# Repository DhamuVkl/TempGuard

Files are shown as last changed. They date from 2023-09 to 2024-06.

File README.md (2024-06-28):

<br/>
<p align="center">
  <a href="https://github.com/dhamuvkl/TempGuard">
    
  </a>

  <h3 align="center">TempGuard</h3>

  <p align="center">
    A sophisticated temperature control system designed for industrial heating applications. It employs a unique approach by utilizing an IRFZ44N MOSFET as a temperature sensor!
    <br/>
    <br/>
  </p>
</p>

    

## Table Of Contents

* [About the Project](#about-the-project)
* [Key Features](#key-features)
* [Technologies Used](#technologies-used)
* [Schematics & Fabrication](#schematics-and-fabrication)
* [Roadmap](#roadmap)
* [Contributing](#contributing)
* [License](#license)
* [Struggles Faced during Development](#struggles-faced-during-development)
* [Author](#author)

## About The Project



**TempGuard** is a sophisticated temperature control system designed for industrial heating applications. It employs a unique approach by utilizing an IRFZ44N MOSFET as a temperature sensor, enabling precise temperature measurements. This innovative system, driven by a BluePill microcontroller (STM32F103C8T6), ensures heating elements operate within desired temperature ranges. Additionally, it features a user interface for seamless adjustments.

##  Key Features: 

* **Overheating Prevention:** TempGuard prevents heating elements from overheating and potential damage, thus extending their operational lifespan.
  
* **Energy Efficiency:** By maintaining an optimal temperature range, the system reduces energy consumption, ultimately lowering electricity bills.  

* **Uniform Heating:** Ensures consistent temperature levels, eliminating issues associated with uneven heating, and thereby enhancing industrial processes.  

* **Versatility:** TempGuard's adaptability extends beyond industrial heating systems, making it suitable for a wide range of applications requiring precise temperature control.  

* **Robust Performance:** Engineered to function reliably under extreme temperature conditions, both in hot and cold environments.

  

## Technologies Used:

* **IRFZ44N MOSFET as Temperature Sensor:** This unconventional choice allows for accurate temperature measurements, enhancing the control of heating elements.

* **BluePill Microcontroller (STM32F103C8T6):** Responsible for crucial tasks including measuring MOSFET temperature values, controlling the relay board, and obtaining user-defined temperature settings.  

* **Relay System:** Vital for regulating the heating element based on the measured temperature values.  

* **User Interface with Switch:** Enables users to toggle between two predefined temperature settings, adding flexibility to the system.  

## Schematics and Fabrication 














## Roadmap

See the [open issues](https://github.com/dhamuvkl/TempGuard/issues) for a list of proposed features (and known issues).

## Contributing

Contributions are what make the open source community such an amazing place to be learn, inspire, and create. Any contributions you make are **greatly appreciated**.
* If you have suggestions for adding or removing projects, feel free to [open an issue](https://github.com/dhamuvkl/TempGuard/issues/new) to discuss it, or directly create a pull request after you edit the *README.md* file with necessary changes.
* Please make sure you check your spelling and grammar.
* Create individual PR for each suggestion.

## Struggles Faced during Development:
coding

* **Analog Prototype with OP-AMP (LM358):** The initial version of the prototype relied on an analog design, utilizing an LM358 OP-AMP in hysteresis mode. However, this approach proved sensitive to Electromagnetic Interference (EMI) during field tests.

* **EMI Sensitivity:** The analog design was susceptible to EMI, especially from electrical noise in the grid. This led to erratic switching of temperature set values, making the system unreliable.  

* **Transition to Digital Design:** To address the EMI sensitivity issue, a significant shift was made towards a digital approach. This involved integrating the BluePill microcontroller (STM32F103C8T6) to bring stability and robustness to the system's operation.

## License

Distributed under the MIT License. See [LICENSE](https://github.com/dhamuvkl/TempGuard/blob/main/LICENSE.md) for more information.

## Author

* **Dharageswaran S** - *Electronics Enthusiast | Innovator | Tech Visionary* - [Dharageswaran S](https://github.com/DhamuVkl/) - *Owner *

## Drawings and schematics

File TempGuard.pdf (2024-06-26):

A

B

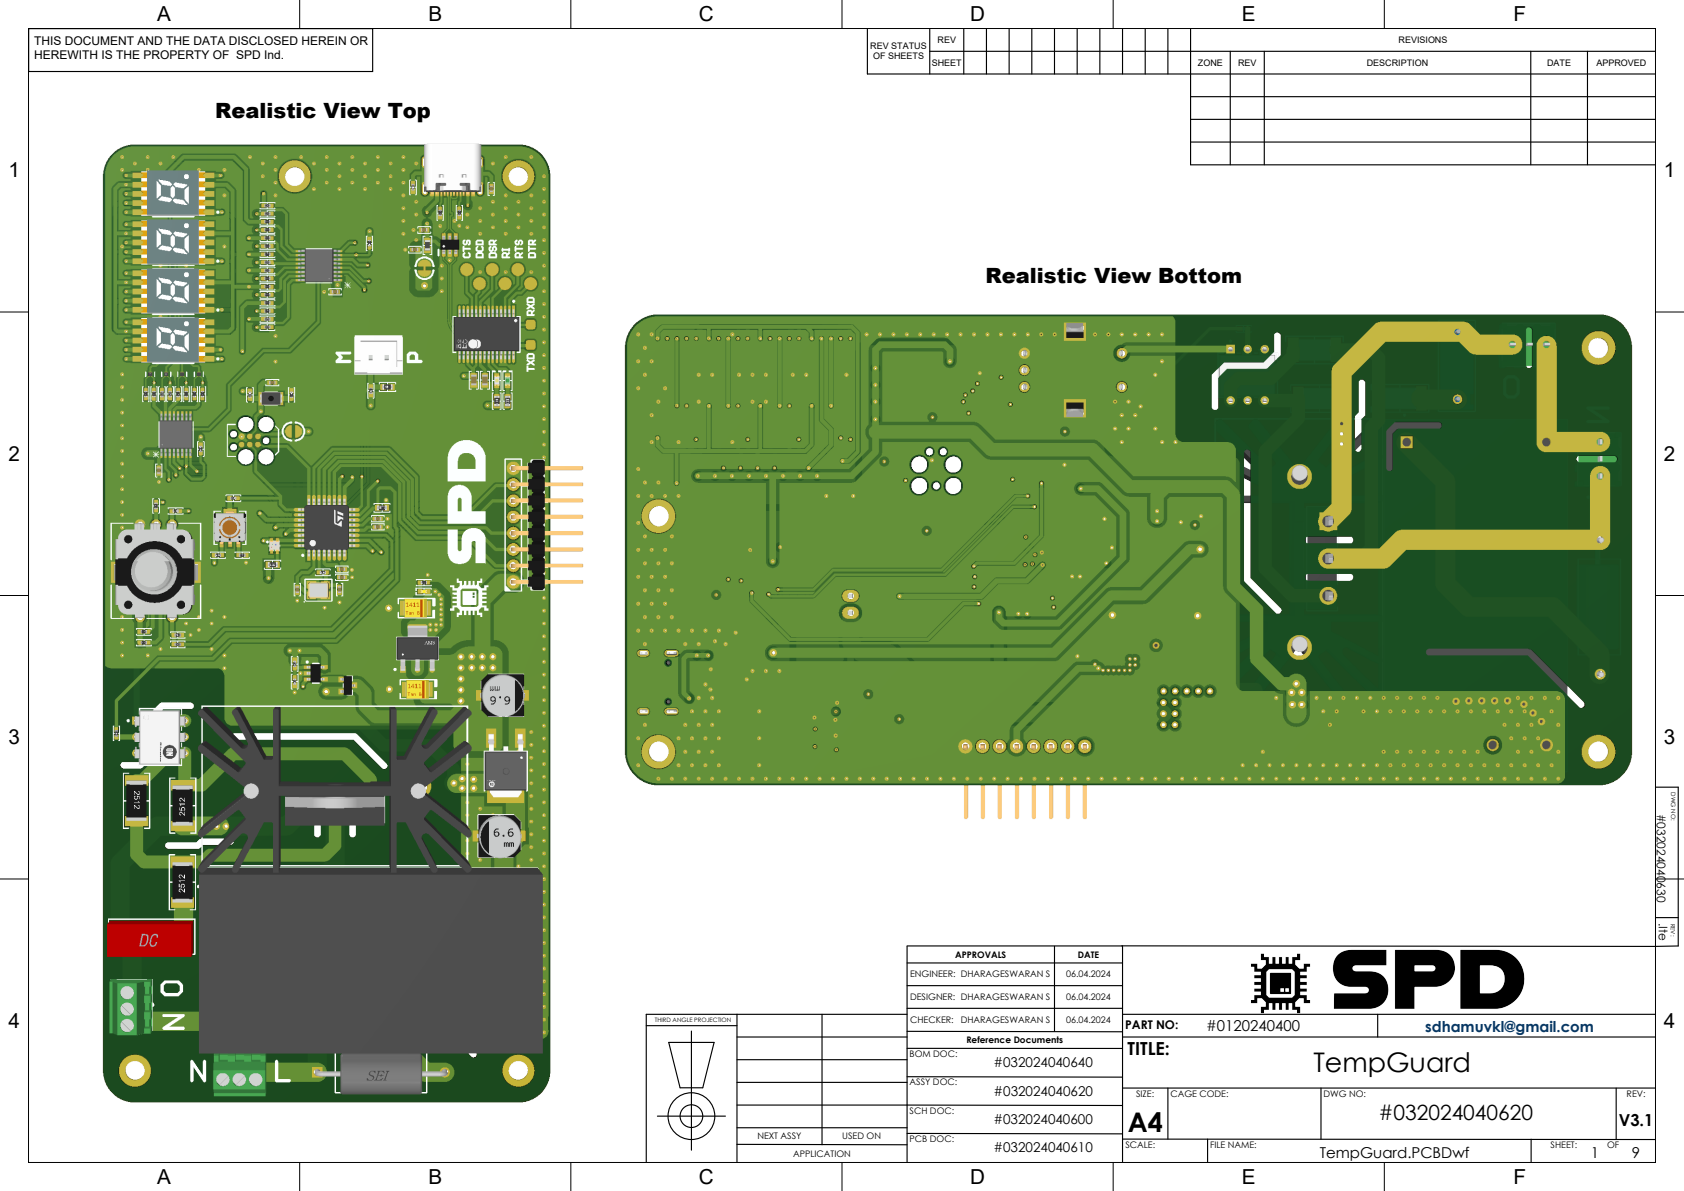
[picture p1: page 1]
sdhamuvkl@gmail.com; ZONE; REV; DESCRIPTION; DATE; APPROVED; REVISIONS; SHEET; REV STATUS OF SHEETS; REV:; SHEET:; DWG NO: #032024040630 .Ite; PART NO:; NEXT ASSY; USED ON; APPLICATION; TempGuard.PCBDwf #032024040610; FILE NAME:; Reference Documents #032024040640; SCH DOC:; PCB DOC:; ASSY DOC:; BOM DOC:; TempGuard; TITLE:; SCALE:; DWG NO:; SIZE:; CAGE CODE:

THIS DOCUMENT AND THE DATA DISCLOSED HEREIN OR
HEREWITH IS THE PROPERTY OF SPD Ind.

Realistic View Top

Realistic View Bottom

APPROVALS | DATE

ENGINEER: DHARAGESWARAN S | 06.04.2024

DESIGNER: DHARAGESWARAN S | 06.04.2024

THIRD ANGLE PROJECTION

CHECKER: DHARAGESWARAN S | 06.04.2024

1 | 1

U2B

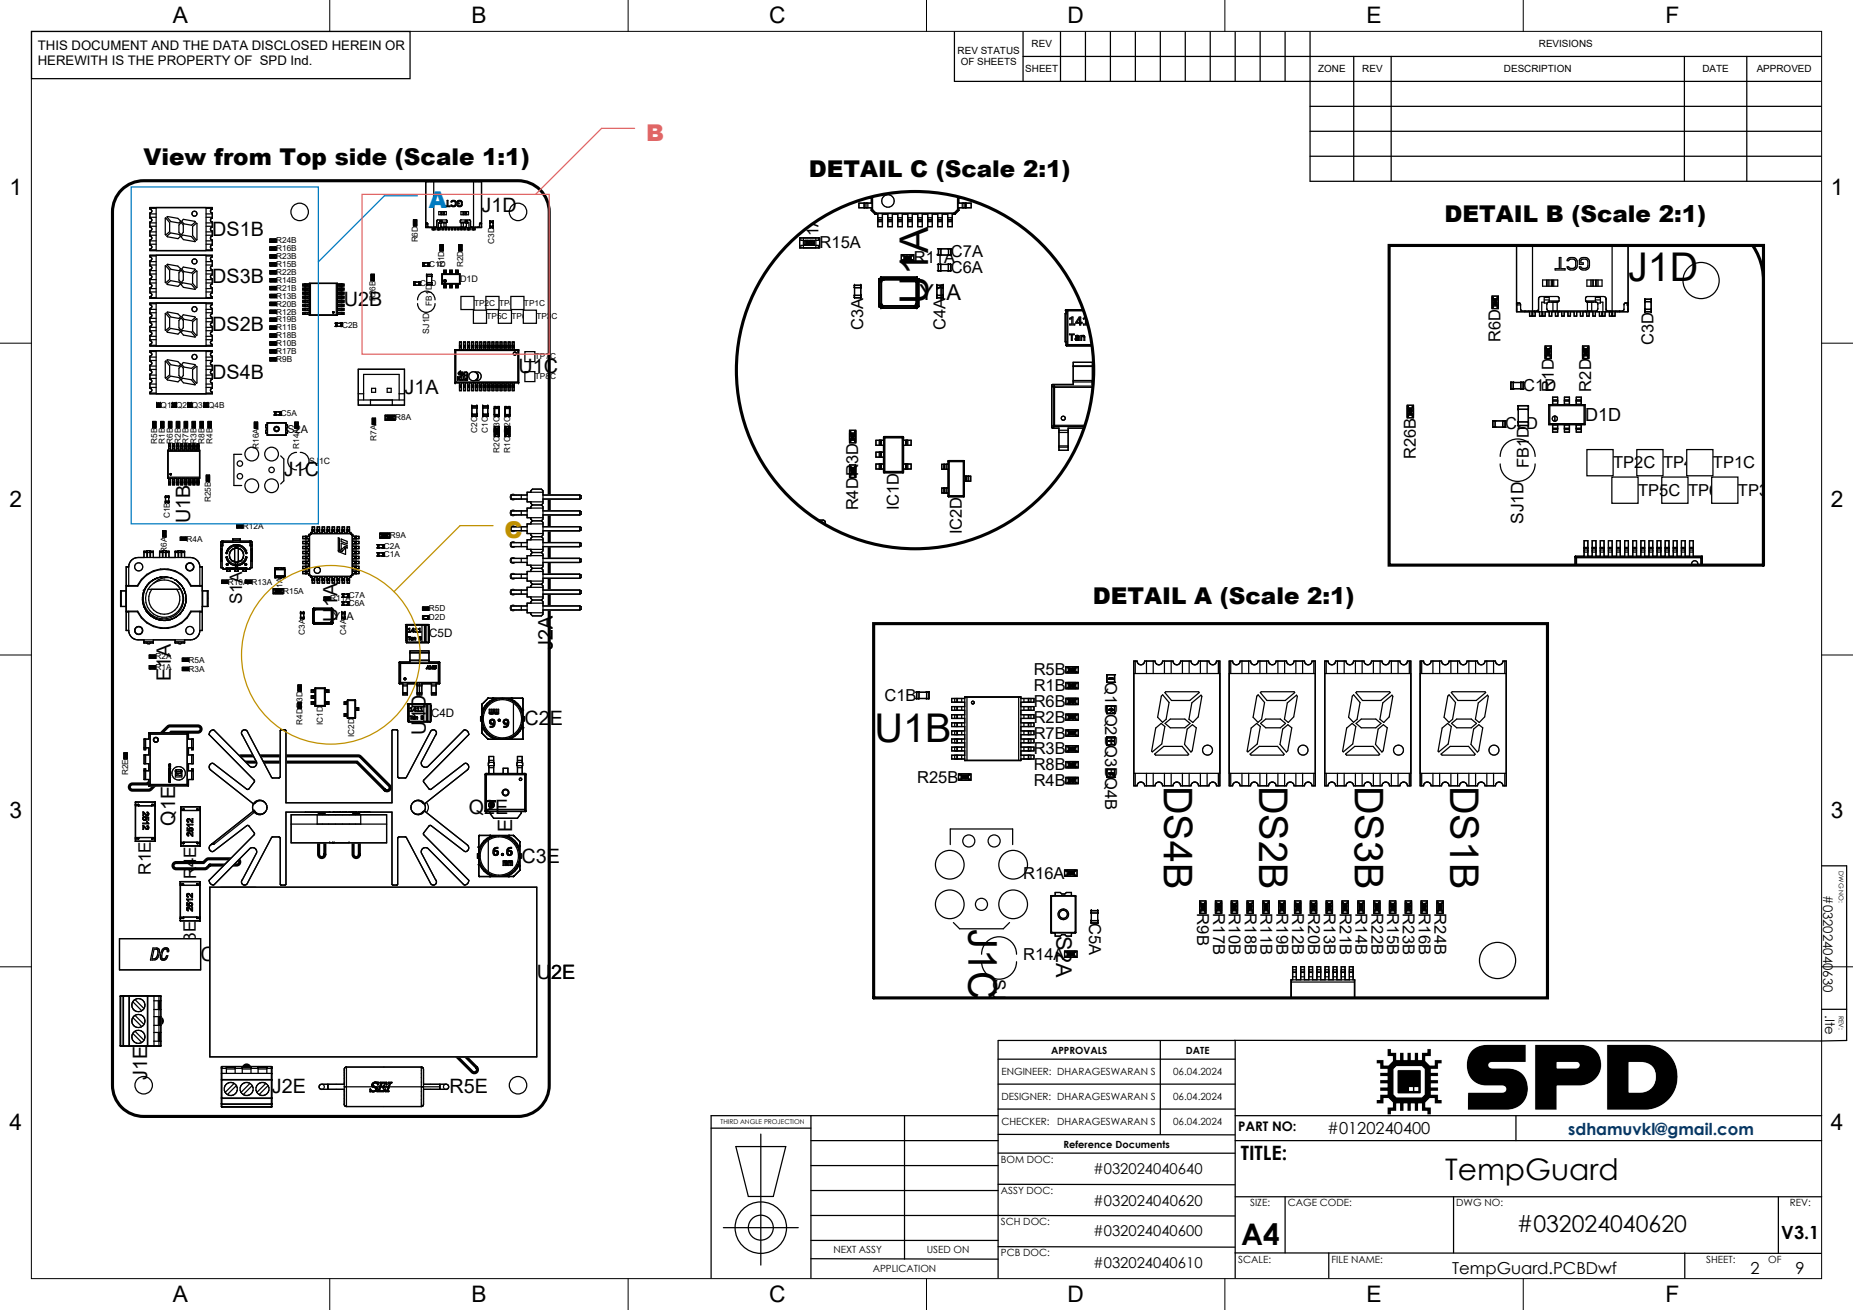
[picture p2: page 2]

View from Top side (Scale 1:1)

1 | 1

# View from Front side (Scale 1:1)

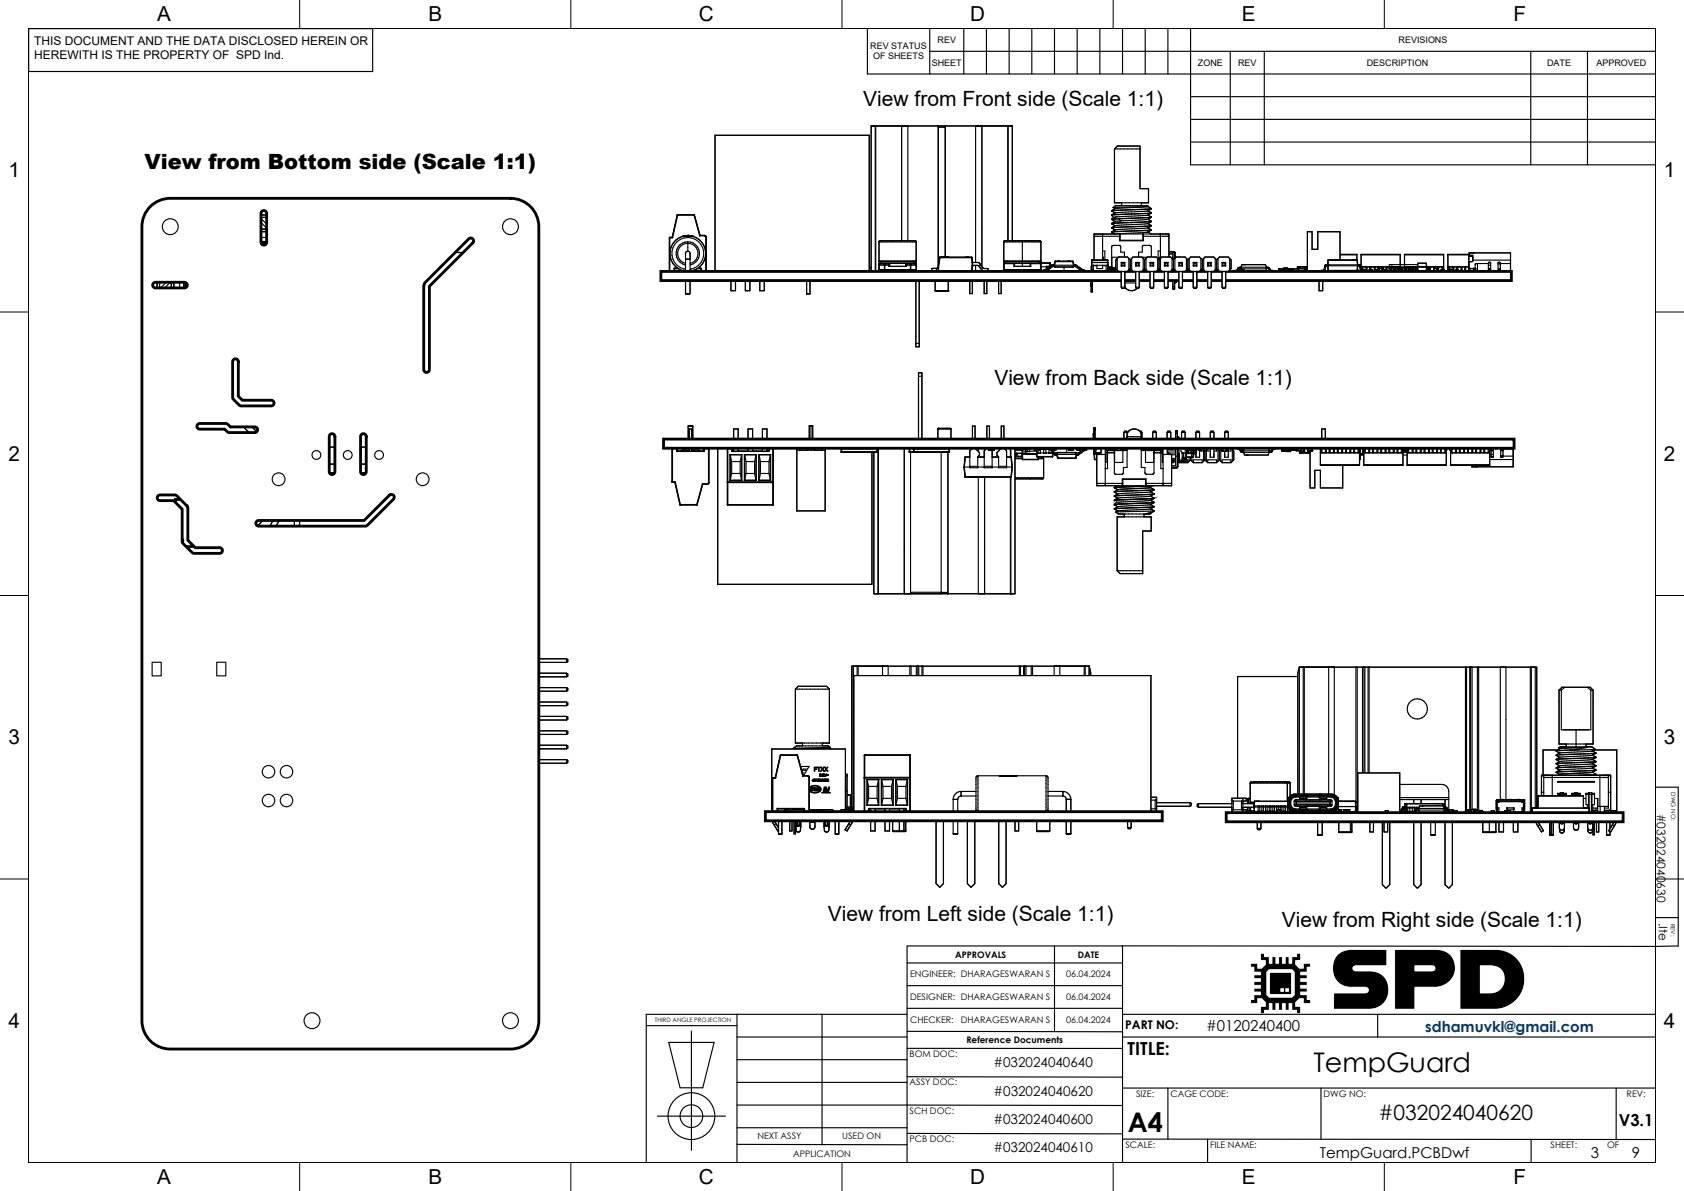
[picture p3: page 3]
DWG NO: #032024040630 .Ite; REV:; DHARAGESWARAN S; CHECKER:; DESIGNER:; ENGINEER:; APPROVALS; DATE; PART NO:; Reference Documents #032024040640; ASSY DOC:; BOM DOC:; TempGuard; TITLE:

View from Bottom side (Scale 1:1)

View from Back side (Scale 1:1)

View from Left side (Scale 1:1)

View from Right side (Scale 1:1)

THIRD ANGLE PROJECTION

sdhamuvkl@gmail.com

1 | 1

# Drill Drawing View (Scale 1.2:1)

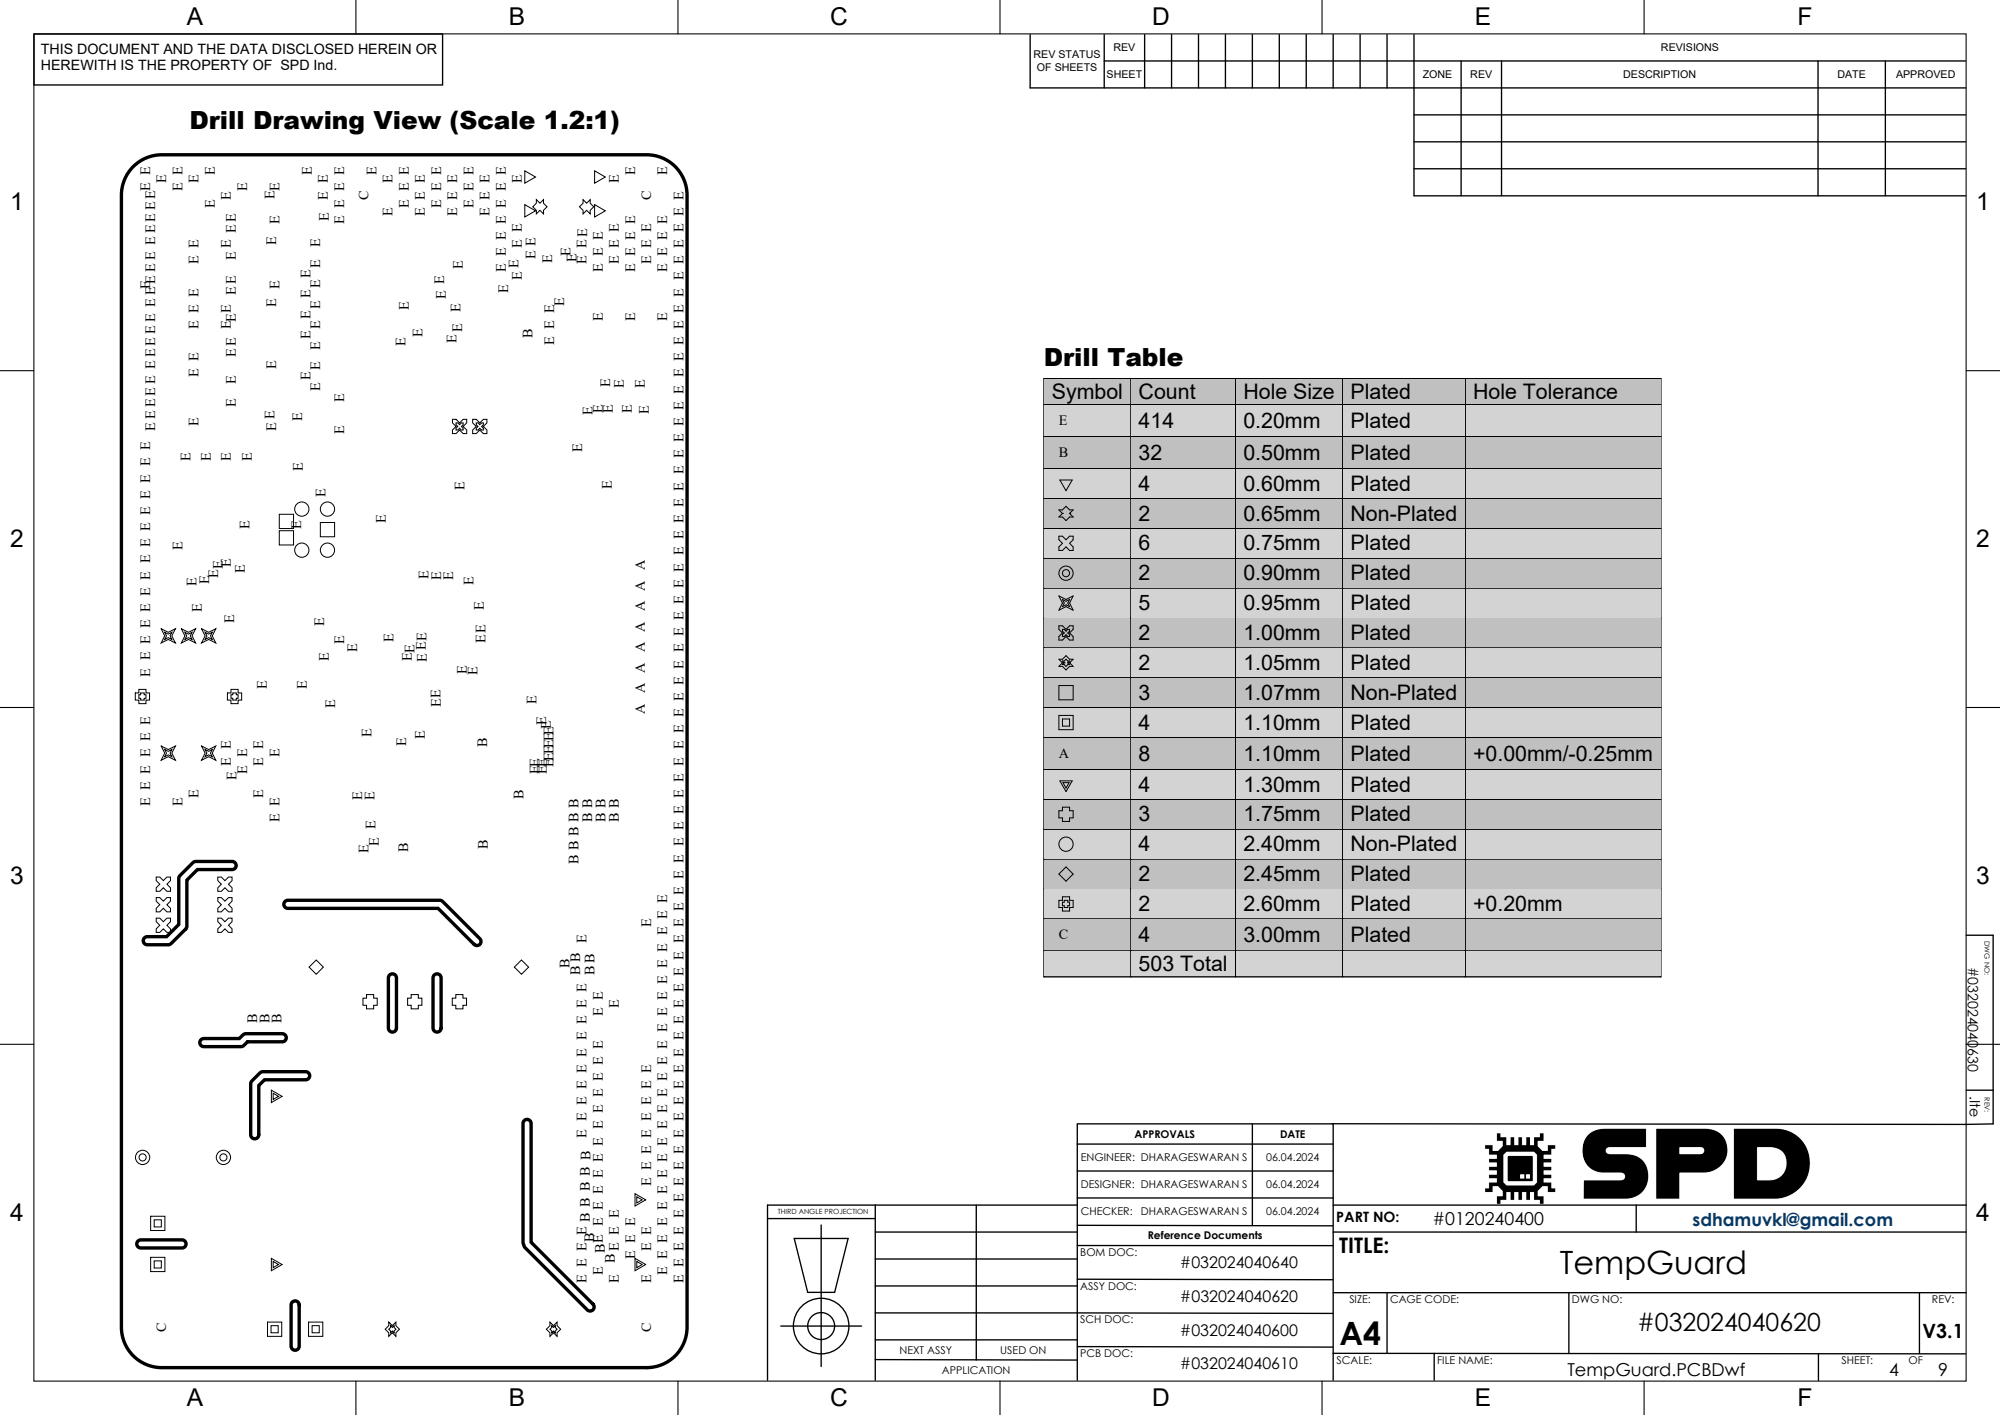
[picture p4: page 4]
B B B B B BBB; EEEE; E E EEE; DWG NO: #032024040630 .Ite; REV:; PART NO:; Reference Documents #032024040640; ASSY DOC:; BOM DOC:; TempGuard; TITLE:; Drill Table

Symbol | Count | Hole Size | Plated | Hole Tolerance
E | 414 | 0.20mm | Plated

B | 32 | 0.50mm | Plated

4 | 0.60mm | Plated
2 | 0.65mm | Non-Plated
6 | 0.75mm | Plated
2 | 0.90mm | Plated

5 | 0.95mm | Plated
2 | 1.00mm | Plated
2 | 1.05mm | Plated
3 | 1.07mm | Non-Plated

4 | 1.10mm | Plated

A | | | 8 | 1.10mm | Plated | +0.00mm/-0.25mm

4 | 1.30mm | Plated
3 | 1.75mm | Plated
4 | 2.40mm | Non-Plated
2 | 2.45mm | Plated
2 | 2.60mm | Plated | +0.20mm

C | | | 4 | 3.00mm | Plated

503 Total

APPROVALS | DATE

ENGINEER: DHARAGESWARAN S | 06.04.2024

DESIGNER: DHARAGESWARAN S | 06.04.2024

THIRD ANGLE PROJECTION

CHECKER: DHARAGESWARAN S | 06.04.2024

sdhamuvkl@gmail.com

1 | 1
Material | Layer | Thickness Dielectric Material Type | Gerber

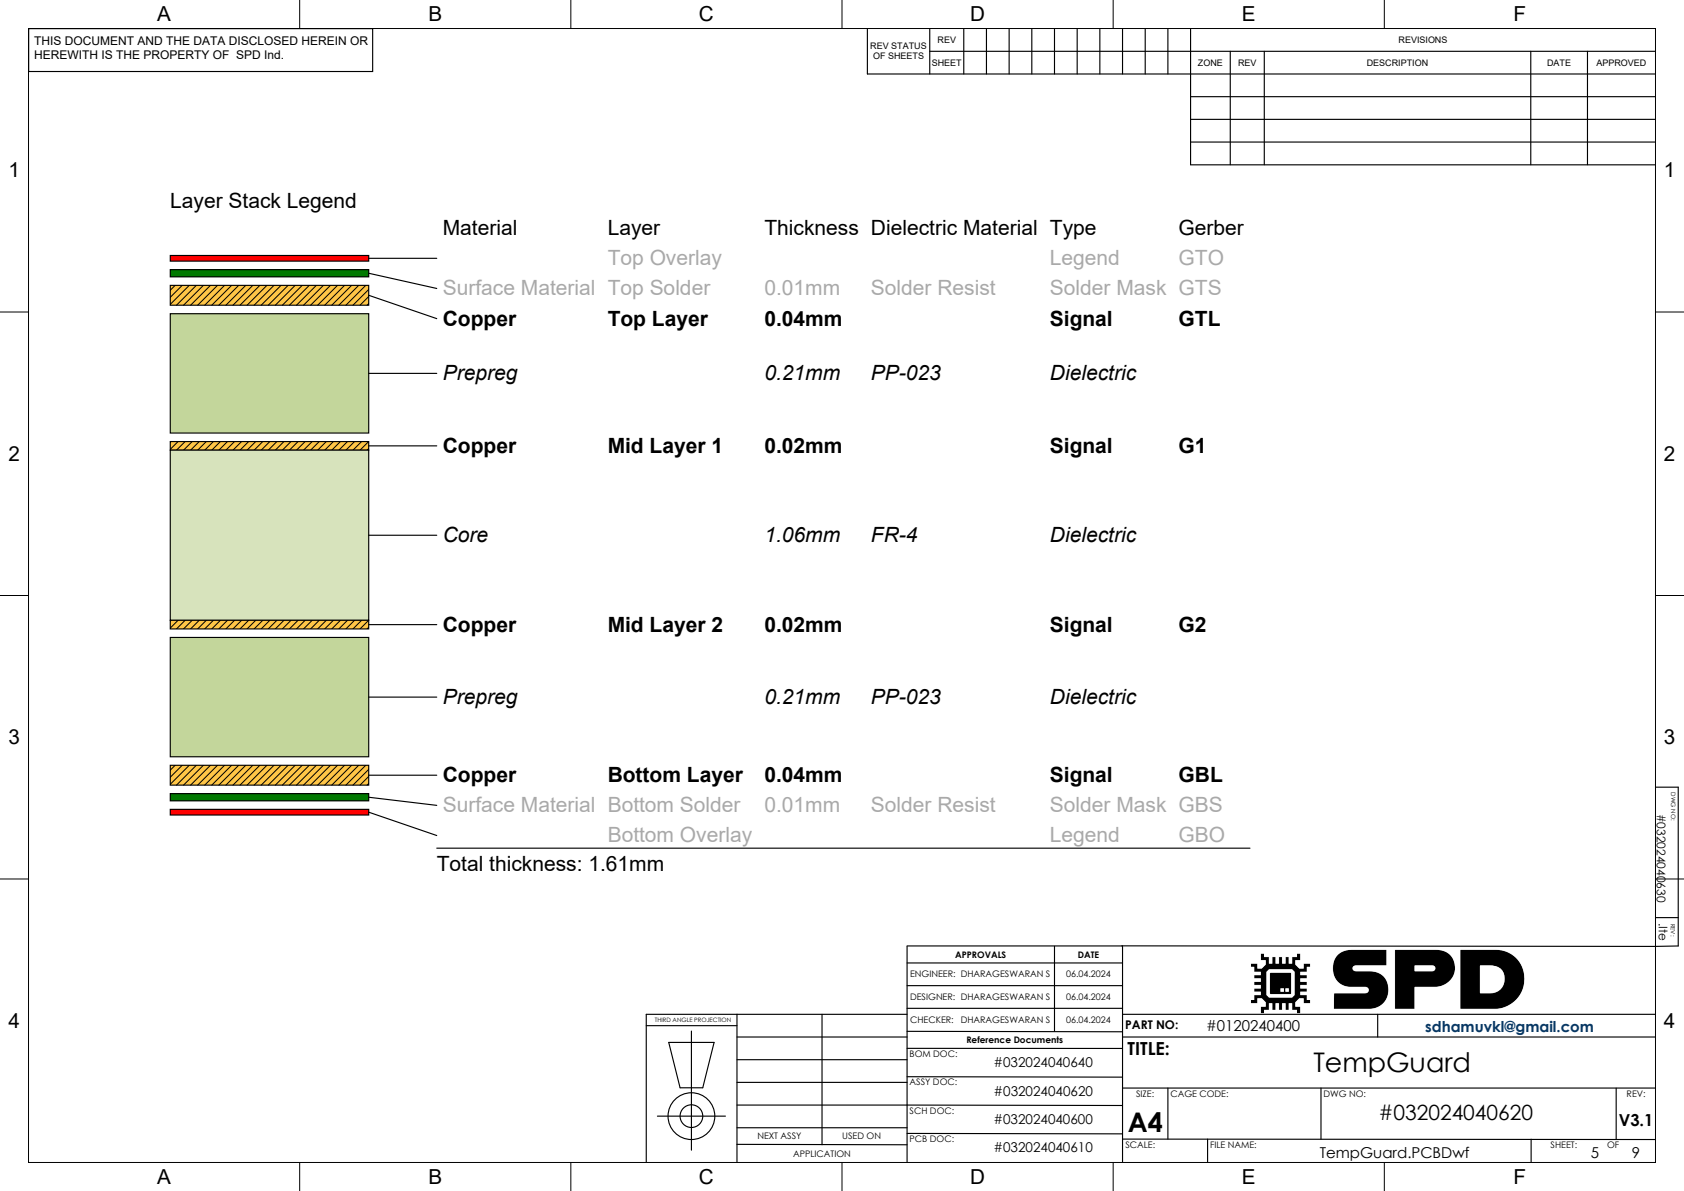
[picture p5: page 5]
sdhamuvkl@gmail.com; DWG NO: #032024040630 .Ite; REV:; PART NO:; Reference Documents #032024040640; ASSY DOC:; BOM DOC:; TempGuard; TITLE:; Top Overlay; Legend; GTO; Surface Material Top Solder; Solder Resist; Solder Mask GTS; Copper; Top Layer; Signal; GTL; Prepreg; Dielectric; Mid Layer 1; Core; Mid Layer 2; Bottom Layer 0.04mm; GBL; Surface Material Bottom Solder 0.01mm; Solder Mask GBS; Bottom Overlay; GBO; Total thickness: 1.61mm

Layer Stack Legend

APPROVALS | DATE

ENGINEER: DHARAGESWARAN S | 06.04.2024

DESIGNER: DHARAGESWARAN S | 06.04.2024

THIRD ANGLE PROJECTION

CHECKER: DHARAGESWARAN S | 06.04.2024

1 | 1

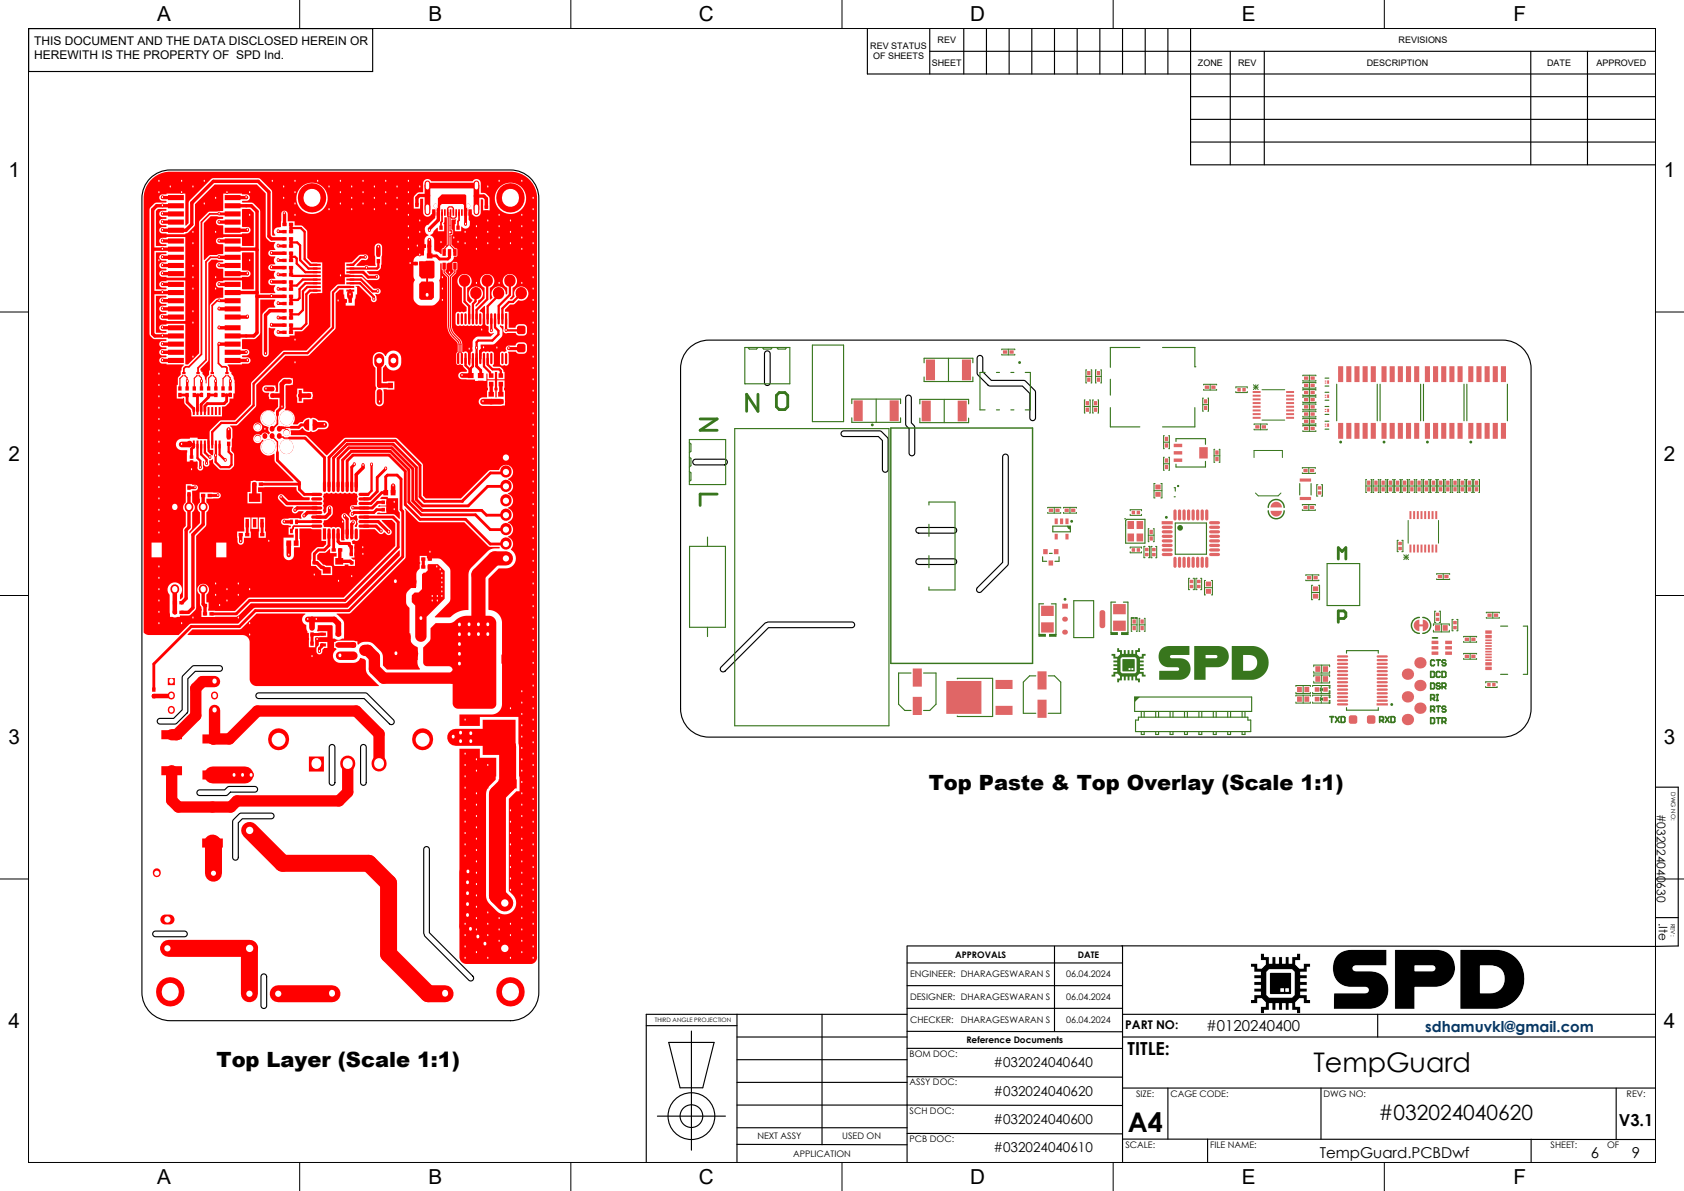
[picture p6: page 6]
DWG NO: #032024040630 .Ite; REV:; PART NO:; Reference Documents #032024040640; ASSY DOC:; BOM DOC:; TempGuard; TITLE:

Top Paste & Top Overlay (Scale 1:1)

APPROVALS | DATE

ENGINEER: DHARAGESWARAN S | 06.04.2024

DESIGNER: DHARAGESWARAN S | 06.04.2024

THIRD ANGLE PROJECTION

CHECKER: DHARAGESWARAN S | 06.04.2024

sdhamuvkl@gmail.com

Top Layer (Scale 1:1)

1 | 1

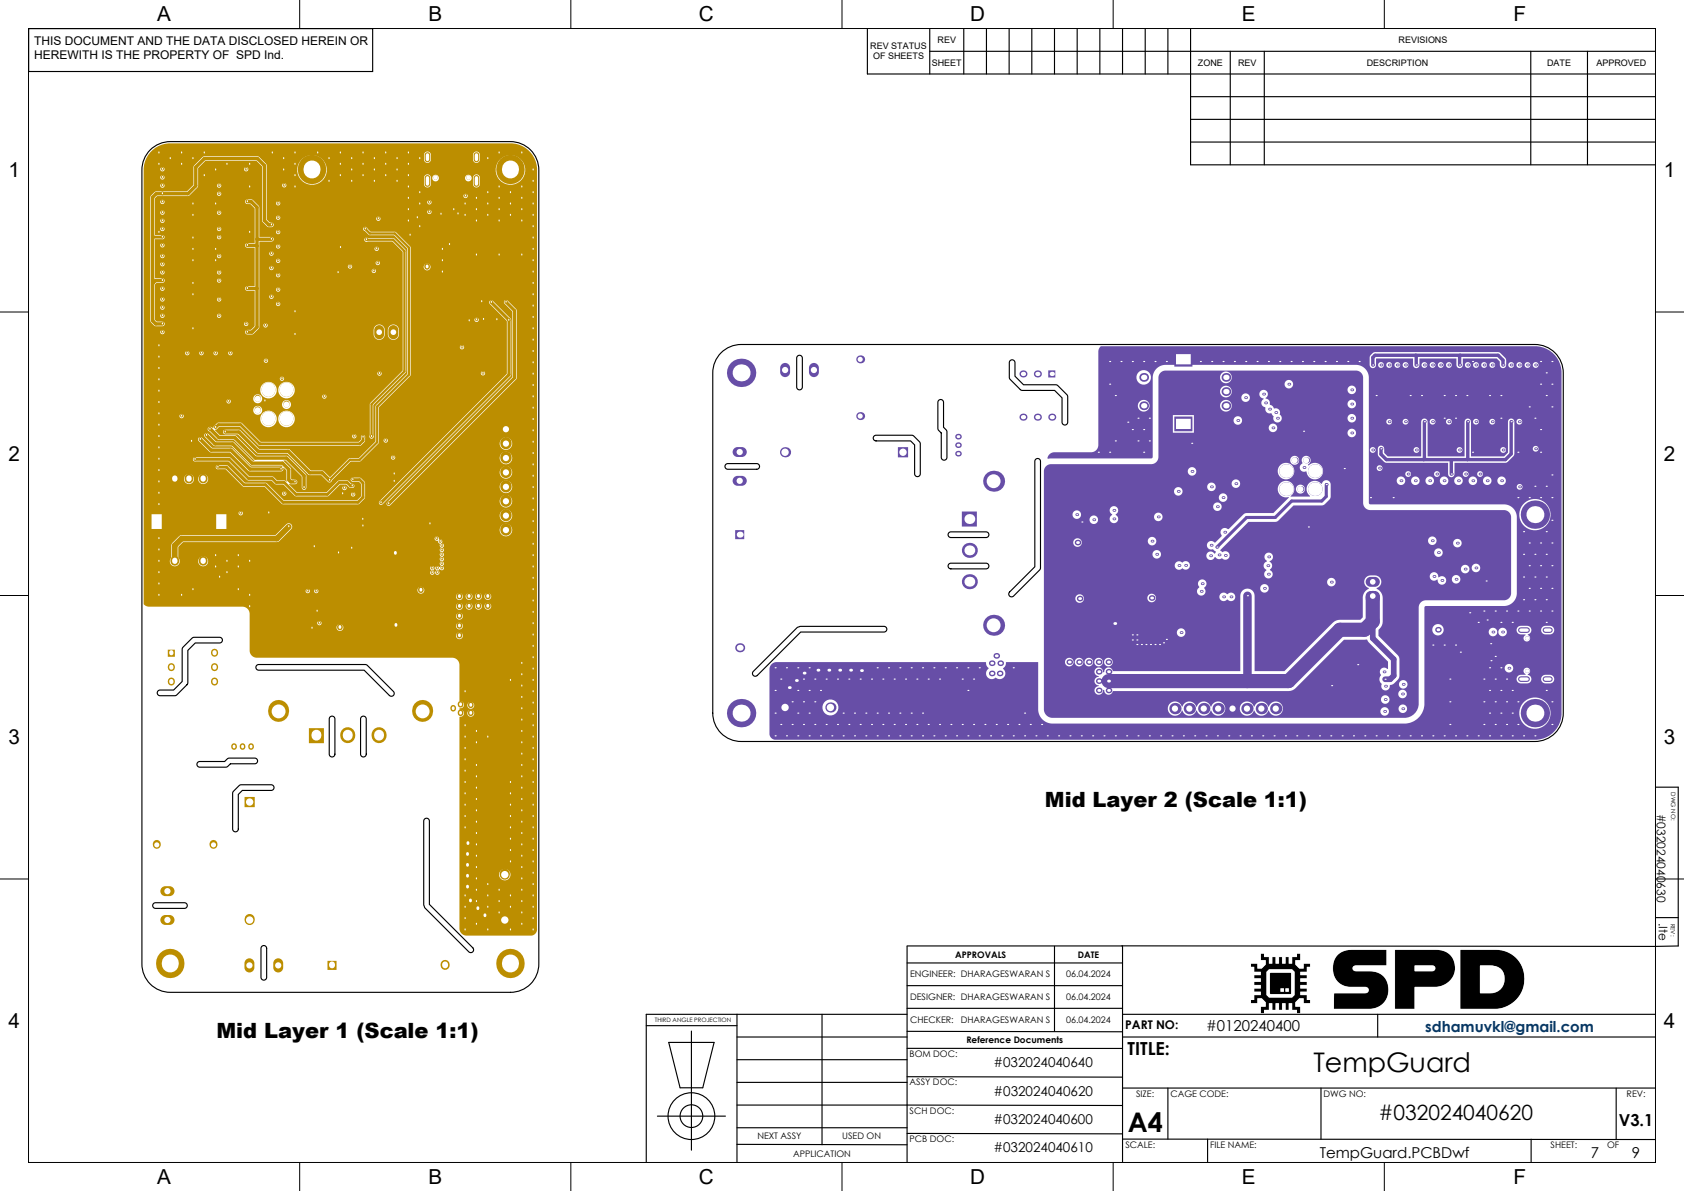
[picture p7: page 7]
DWG NO: #032024040630 .Ite; REV:; PART NO:; Reference Documents #032024040640; ASSY DOC:; BOM DOC:; TempGuard; TITLE:

Mid Layer 2 (Scale 1:1)

APPROVALS | DATE

ENGINEER: DHARAGESWARAN S | 06.04.2024

DESIGNER: DHARAGESWARAN S | 06.04.2024

Mid Layer 1 (Scale 1:1)

THIRD ANGLE PROJECTION

CHECKER: DHARAGESWARAN S | 06.04.2024

sdhamuvkl@gmail.com

1 | 1
Bottom Layer (Scale 1:1) | Bottom Solder (Scale 1:1)

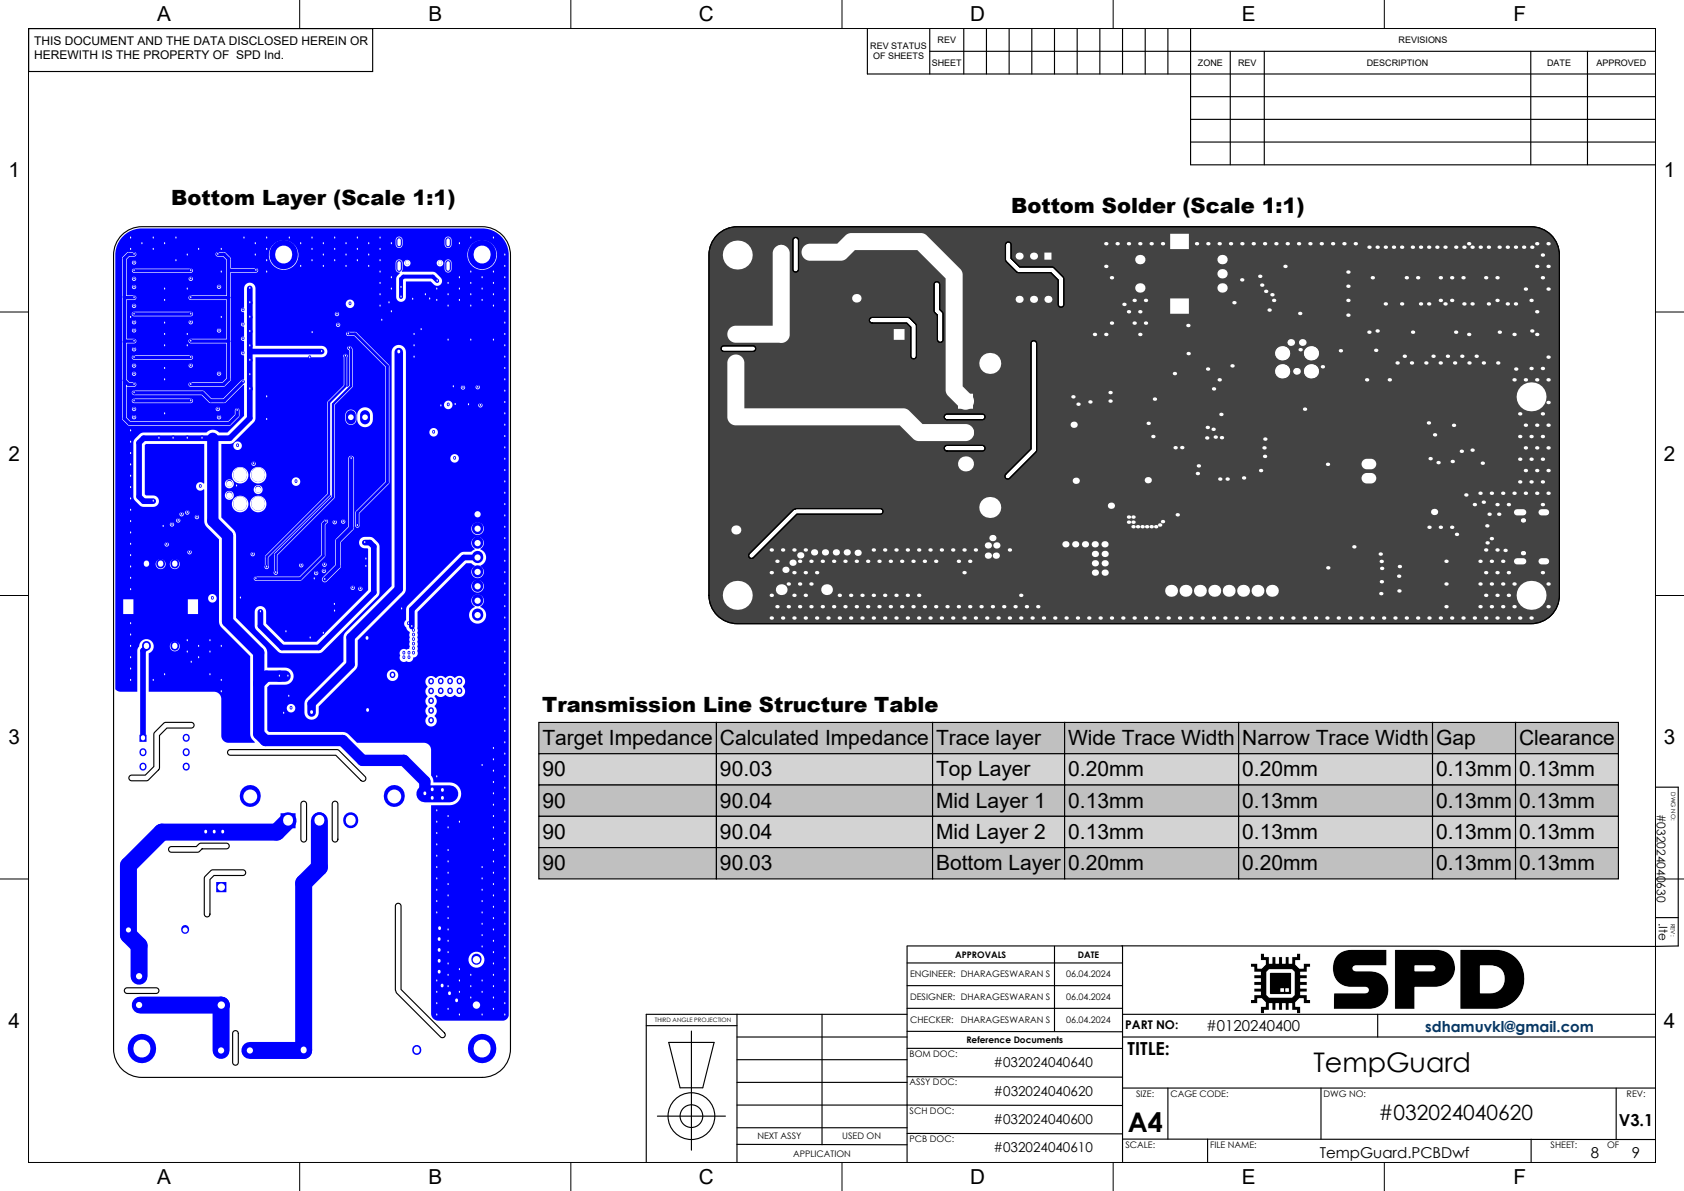
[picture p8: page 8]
DWG NO: #032024040630 .Ite; REV:; PART NO:; Reference Documents #032024040640; ASSY DOC:; BOM DOC:; TempGuard; TITLE:; Target Impedance 90 90 90 90; Calculated Impedance 90.03 90.04 90.04 90.03; Trace layer Top Layer Mid Layer 1 Mid Layer 2 Bottom Layer; Wide Trace Width 0.20mm 0.13mm 0.13mm 0.20mm; Narrow Trace Width 0.20mm 0.13mm 0.13mm 0.20mm; Gap 0.13mm 0.13mm 0.13mm 0.13mm; Clearance 0.13mm 0.13mm 0.13mm 0.13mm; Transmission Line Structure Table

APPROVALS | DATE

ENGINEER: DHARAGESWARAN S | 06.04.2024

DESIGNER: DHARAGESWARAN S | 06.04.2024

THIRD ANGLE PROJECTION

CHECKER: DHARAGESWARAN S | 06.04.2024

sdhamuvkl@gmail.com

1 | 1
Designator | Name | Quantity

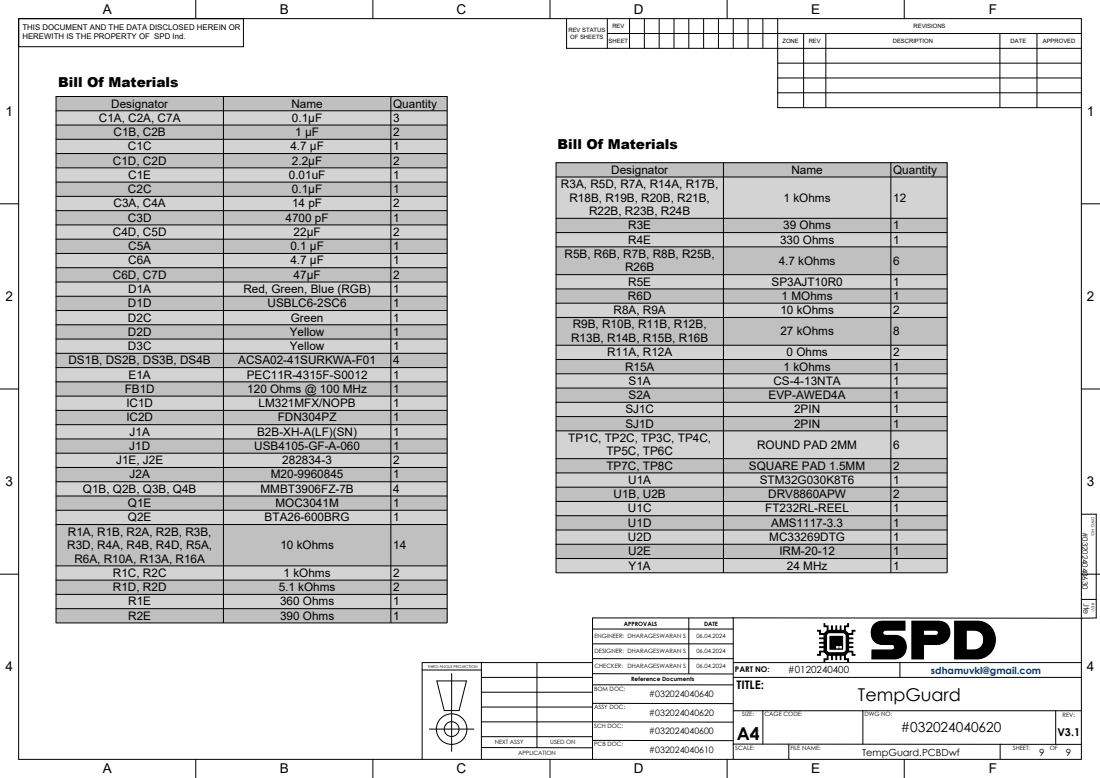
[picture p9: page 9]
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

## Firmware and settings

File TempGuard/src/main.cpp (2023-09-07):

#include <Arduino.h>

const int relayPin = PC13;
const int temperaturePin = PA5;
const int lowThresholdPotPin = PA0;
const int highThresholdPotPin = PA1;
const int switchPin = PC14;  // Switch input pin
const int redLedPin = PB7;    // PWM output pin for red LED
const int greenLedPin = PB6;  // PWM output pin for green LED
const int pwmFrequency = 1000;  // PWM frequency in Hz


int lowThreshold = 0;
int highThreshold = 0;
unsigned long previousMillis = 0;
int brightness = 0;
int fadeAmount = 5;  // Rate of brightness change
unsigned long delayInterval = 1000;  // Delay interval in milliseconds
const int numReadings = 20;  // Number of temperature readings for averaging
int temperatureReadings[numReadings];  // Array to store temperature readings
int lowThresholdReadings[numReadings];  // Array to store lowThresholdPot readings
int highThresholdReadings[numReadings];  // Array to store highThresholdPot readings
int currentReading = 0;  // Index of the current reading
int averageTemperature = 0;  // Average temperature value
int averageLowThreshold = 0;  // Average lowThresholdPot value
int averageHighThreshold = 0;  // Average highThresholdPot value
bool switchState = false;  // State of the switch

void setup() {

  pinMode(relayPin, OUTPUT);
  digitalWrite(relayPin, LOW);  // Set relay pin to LOW using internal pulldown resistor
  pinMode(redLedPin, OUTPUT);
  pinMode(greenLedPin, OUTPUT);
  pinMode(switchPin, INPUT_PULLDOWN);  // Set switch pin as input with internal pull-down resistor


  pinMode(temperaturePin, INPUT_ANALOG);
  pinMode(lowThresholdPotPin, INPUT_ANALOG);
  pinMode(highThresholdPotPin, INPUT_ANALOG);


  Serial.begin(9600);
}

void loop() {
  // Current time
  unsigned long currentMillis = millis();

  // Check if the delay interval has passed
  if (currentMillis - previousMillis >= delayInterval) {
    previousMillis = currentMillis; // Update the previous time

    // Read analog values
    int temperatureValue = analogRead(temperaturePin);

    // Store the current readings in the arrays
    temperatureReadings[currentReading] = temperatureValue;
    lowThresholdReadings[currentReading] = analogRead(lowThresholdPotPin);
    highThresholdReadings[currentReading] = analogRead(highThresholdPotPin);

    // Move to the next reading index
    currentReading++;
    if (currentReading >= numReadings) {
      currentReading = 0;  // Reset the reading index
    }

    // Calculate the average temperature
    averageTemperature = 0;
    for (int i = 0; i < numReadings; i++) {
      averageTemperature += temperatureReadings[i];
    }
    averageTemperature /= numReadings;

    // Calculate the average lowThresholdPot value
    averageLowThreshold = 0;
    for (int i = 0; i < numReadings; i++) {
      averageLowThreshold += lowThresholdReadings[i];
    }
    averageLowThreshold /= numReadings;

    // Calculate the average highThresholdPot value
    averageHighThreshold = 0;
    for (int i = 0; i < numReadings; i++) {
      averageHighThreshold += highThresholdReadings[i];
    }
    averageHighThreshold /= numReadings;

    int mappedTemperature = map(averageTemperature, 0, 4095, 0, 100);
    lowThreshold = map(averageLowThreshold, 0, 4095, 60, 100);

 
    switchState = digitalRead(switchPin);

    if (switchState) {
      // Switch is in the high state, increment highThreshold by 4 points
      highThreshold = map(averageHighThreshold, 0, 4095, 75, 95) + 4;
    } else {
      // Switch is in the low state, use highThresholdPot value as it is
      highThreshold = map(averageHighThreshold, 0, 4095, 75, 95);
    }

    // Print values
    Serial.print("Temperature Value: ");
    Serial.print(mappedTemperature);
    Serial.print("\tLow Threshold: ");
    Serial.print(lowThreshold);
    Serial.print("\tHigh Threshold: ");
    Serial.print(highThreshold);

    // Compare values and control relay
    if (mappedTemperature > highThreshold) {
      digitalWrite(relayPin, HIGH);  // Turn off the relay
      fadeAmount = -15;  // Decrease brightness
      Serial.println("\tRelay OFF");
    } else if (mappedTemperature <= lowThreshold) {
      digitalWrite(relayPin, LOW);  // Turn on the relay
      fadeAmount = 15;  // Increase brightness
      Serial.println("\tRelay ON");
    } else {
      //digitalWrite(relayPin, LOW);  // Set relay pin to LOW using internal pulldown resistor
      Serial.println("\t");
    }

    // Update LED brightness
    brightness += fadeAmount;
    if (brightness <= 0 || brightness >= 255) {
      // Reverse the fade direction
      fadeAmount = -fadeAmount;
    }

    if (mappedTemperature >= lowThreshold && mappedTemperature <= highThreshold) {
      // Adjust brightness levels based on temperature
      int brightnessRed = map(mappedTemperature, lowThreshold, highThreshold, 0, 255);
      int brightnessGreen = map(mappedTemperature, lowThreshold, highThreshold, 255, 0);
      analogWrite(redLedPin, brightnessRed);
      analogWrite(greenLedPin, brightnessGreen);
    } else {
      // Use default brightness
      analogWrite(redLedPin, brightness);
      analogWrite(greenLedPin, 255 - brightness);
    }
  }
}
